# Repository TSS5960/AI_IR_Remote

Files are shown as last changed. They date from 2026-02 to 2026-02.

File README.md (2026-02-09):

# ESP32-S3 Smart AC Remote Control with Voice Integration

An intelligent air conditioner remote control system based on ESP32-S3 with voice wake word detection (Edge Impulse), IR learning, cloud connectivity, and multi-sensor integration.

## Features

### Core Functionality
- **WiFi Captive Portal**: Easy WiFi setup via web interface (no hardcoded credentials)
- **IR Control**: Send IR commands to control air conditioners (10+ brands supported)
- **IR Learning**: Capture and replay any IR remote signals (up to 40 signals)
- **Voice Wake Word**: "Hey Bob" wake word detection using Edge Impulse ML
- **Multi-Screen Display**: TFT interface with 7 different screens
- **Environmental Monitoring**: Temperature, humidity, light, and motion sensors
- **Cloud Integration**: MQTT broker and Firebase real-time database
- **Web Dashboard**: Cloudflare-hosted control panel
- **Alarm System**: Time-based alarms with speaker notifications

### Voice Features
- **Edge Impulse Wake Word**: On-device ML model for "Hey Bob" detection
  - Runs entirely on ESP32 (no cloud required)
  - ~100ms inference latency
  - Adjustable confidence threshold (default 80%)
- **Speech Recognition**: Experimental integration with Groq console
  - Uses console.groq.com for speech-to-text transcription
  - Currently in experimental phase
  - Requires internet connection
- **Record & Playback**: 3-second audio recording with instant playback
- **Voice Level Monitor**: Real-time audio RMS visualization
- **LED Feedback**: NeoPixel RGB LED indicates wake word detection and processing states

## Hardware Components

### Main Controller
- **ESP32-S3-N16R8** - Dual-core 240MHz with 16MB Flash, 8MB PSRAM

### Audio System
- **INMP441 I2S MEMS Microphone** (GPIO4=WS, GPIO5=SCK, GPIO6=SD)
- **MAX98357 I2S Amplifier + Speaker** (GPIO15=BCLK, GPIO16=LRCLK, GPIO7=DIN)
- **Adafruit NeoPixel RGB LED** (GPIO48)

### Display & Input
- **ST7789 TFT Display** (240x280, SPI)
- **Analog Joystick** (X/Y axes + button)

### Sensors
- **BH1750 Light Sensor** (I2C)
- **DHT11 Temperature & Humidity Sensor**
- **PIR Motion Sensor**

### IR System
- **IR Transmitter LED** (GPIO12)
- **IR Receiver Module** (GPIO11)

## Project Structure

```
AC_IR_Remote/
├── AC_IR_Remote.ino          # Main firmware
├── config.h                   # Pin assignments and configuration
├── secrets.h                  # Firebase credentials (not in git)
├── secrets.h.template         # Template for secrets configuration
├── firebase_config.h          # Firebase paths (not in git)
├── firebase_config.h.template # Template for Firebase configuration
│
├── # Core modules
├── ac_control.cpp/h           # AC IR control logic
├── ir_control.cpp/h           # IR transmitter/receiver
├── ir_learning_enhanced.cpp/h # Enhanced IR learning mode
├── mic_control.cpp/h          # Microphone I2S driver
├── speaker_control.cpp/h      # Audio playback
├── button_control.cpp/h       # Joystick input handling
├── display.cpp/h              # TFT screen management
├── sensors.cpp/h              # Environmental sensors
├── alarm_manager.cpp/h        # Alarm system
│
├── # Edge Impulse Wake Word
├── ei_wake_word.cpp/h         # Edge Impulse integration
│
├── # Network modules
├── wifi_manager.cpp/h         # WiFi connectivity
├── mqtt_broker.cpp/h          # MQTT client
├── firebase_client.cpp/h      # Firebase integration
│
├── # Training Tools
├── EiWakeWordTraining/        # Audio sample collection tools
│   ├── audio_capture.ino      # ESP32 sketch for recording samples
│   └── capture_samples.py     # Python script to save WAV files
│
├── guide/                     # Documentation (gitignored)
│   └── EDGE_IMPULSE_GUIDE.md  # Complete Edge Impulse setup guide
│
└── cloudflare_dashboard/      # Web dashboard
    ├── src/index.js           # Cloudflare Worker
    ├── public/
    │   ├── index.html         # Dashboard UI
    │   ├── app.js             # Frontend logic
    │   └── styles.css         # Styling
    ├── wrangler.toml          # Cloudflare configuration (not in git)
    └── wrangler.toml.template # Template for Cloudflare configuration
```

## Getting Started

### 1. Hardware Setup

**Display (ST7789 240x280):**
```
ST7789 TFT → ESP32-S3
  VCC  → 3.3V
  GND  → GND
  MOSI → GPIO47
  SCLK → GPIO21
  DC   → GPIO40
  RST  → GPIO45
  BL   → GPIO42
  CS   → Not connected (directly enabled)
```

**Audio System:**
```
INMP441 Microphone → ESP32-S3
  VDD → 3.3V
  GND → GND
  WS  → GPIO4
  SCK → GPIO5
  SD  → GPIO6
  L/R → GND

MAX98357 Amplifier → ESP32-S3
  VIN  → 5V
  GND  → GND
  BCLK → GPIO15
  LRC  → GPIO16
  DIN  → GPIO7

NeoPixel RGB LED → ESP32-S3
  VDD → 5V
  GND → GND
  DIN → GPIO48
```

**IR System:**
```
IR Transmitter → ESP32-S3
  VCC → 3.3V
  GND → GND
  DAT → GPIO8

IR Receiver → ESP32-S3
  VCC → 3.3V
  GND → GND
  OUT → GPIO9
```

**Sensors:**
```
DHT11 → ESP32-S3
  VCC  → 3.3V
  GND  → GND
  DATA → GPIO17

BH1750 Light Sensor → ESP32-S3
  VCC → 3.3V
  GND → GND
  SDA → GPIO14
  SCL → GPIO13

PIR Motion Sensor → ESP32-S3
  VCC → 5V
  GND → GND
  OUT → GPIO10
```

**Joystick:**
```
Analog Joystick → ESP32-S3
  VCC → 3.3V
  GND → GND
  VRx → GPIO1
  VRy → GPIO2
  SW  → GPIO18
```

### 2. Software Setup

#### Arduino IDE Configuration
1. Install ESP32 board support: https://espressif.github.io/arduino-esp32/
2. Select Board: **ESP32S3 Dev Module**
3. Install required libraries:
   - `Adafruit_NeoPixel`
   - `TFT_eSPI`
   - `IRremoteESP8266`
   - `DHT sensor library`
   - `BH1750`
   - `Firebase ESP32 Client`
   - `PubSubClient`
   - **Edge Impulse library** (see Wake Word Setup below)

#### TFT_eSPI Library Configuration

**Important:** The TFT_eSPI library requires manual pin configuration inside the library folder. (Don't ask me why, ask the creator of this library: https://github.com/Bodmer/TFT_eSPI)

1. Navigate to your Arduino libraries folder:
   ```
   Windows: C:\Users\<username>\Documents\Arduino\libraries\TFT_eSPI\
   Mac/Linux: ~/Arduino/libraries/TFT_eSPI/
   ```

2. Open `User_Setup.h` and make these changes:

   ```cpp
   // Comment out the default driver and enable ST7789:
   // #define ILI9341_DRIVER
   #define ST7789_DRIVER

   // Set display size (240x280 for this project):
   #define TFT_WIDTH  240
   #define TFT_HEIGHT 280

   // Define the pins for ESP32-S3:
   #define TFT_MOSI 47
   #define TFT_SCLK 21
   #define TFT_CS   -1  // Not used (directly connected)
   #define TFT_DC   40
   #define TFT_RST  45
   #define TFT_BL   42  // Backlight (optional, controlled in code)

   // Enable hardware SPI:
   #define USE_HSPI_PORT
   ```

3. Save the file and restart Arduino IDE.

**Note:** Backlight control is handled separately in `config.h` via `TFT_BL_PIN`.

#### Upload Firmware
1. Connect ESP32-S3 via USB
2. Select correct port in Arduino IDE
3. Upload `AC_IR_Remote.ino`
4. Open Serial Monitor at **115200 baud**

### 3. Wake Word Setup (Edge Impulse)

The wake word detection uses Edge Impulse for on-device machine learning. Follow these steps to train your own "Hey Bob" model:

#### Step 1: Collect Training Samples

Use the tools in `EiWakeWordTraining/` folder:

1. **Upload the capture sketch:**
   ```
   Open EiWakeWordTraining/audio_capture.ino in Arduino IDE
   Upload to ESP32
   Close Serial Monitor after upload
   ```

2. **Install Python dependencies:**
   ```bash
   pip install pyserial
   ```

3. **Run the capture script:**
   ```bash
   cd EiWakeWordTraining
   python capture_samples.py
   ```

4. **Record samples interactively:**
   ```
   Commands:
     1 or h  - Record 'hey_bob' sample (say "Hey Bob")
     2 or n  - Record 'noise' sample (background sounds)
     3 or u  - Record 'unknown' sample (other words)
     t       - Test microphone level
     s       - Show sample counts
     q       - Quit
   ```

5. **Recommended sample counts:**
   - `hey_bob`: 50-100 samples (vary your voice, distance, speed)
   - `noise`: 200+ samples (silence, fan noise, TV, typing)
   - `unknown`: 30-50 samples ("Hello", "Hey John", "OK Google", etc.)

6. **Samples are saved to:** `EiWakeWordTraining/training_samples/`

**Important:** Close Arduino IDE Serial Monitor before running Python script - only one program can use the COM port.

#### Step 2: Train on Edge Impulse

1. Create account at [edgeimpulse.com](https://edgeimpulse.com)
2. Create new project: "Hey Bob Wake Word"
3. Upload WAV files from `training_samples/` folders with correct labels
4. Create Impulse:
   - Window size: 1500ms, Stride: 500ms, Frequency: 16000Hz
   - Processing: Audio (MFCC)
   - Learning: Classification or Transfer Learning
5. Train model (target >90% accuracy)
6. Deploy as Arduino library (Quantized int8)
7. Download the `.zip` file

#### Step 3: Install Library

1. In Arduino IDE: **Sketch** → **Include Library** → **Add .ZIP Library**
2. Select the downloaded Edge Impulse library
3. Re-upload `AC_IR_Remote.ino`

The wake word detection will automatically start on boot.

### 4. WiFi Setup (Captive Portal)

1. **First boot** - ESP32 creates WiFi AP: `ESP32_AC_Remote`
2. **Connect to AP** - WiFi password: `12345678`
3. **Configure WiFi** - Browser auto-opens configuration page
   - If not, navigate to `http://192.168.4.1`
   - Enter your WiFi SSID and password
4. **Device reboots** and connects to your WiFi network

### 5. Firebase Setup

1. Copy templates:
   ```bash
   cp firebase_config.h.template firebase_config.h
   cp secrets.h.template secrets.h
   ```

2. Edit with your Firebase credentials

## Usage

### Serial Commands

**Wake Word (Edge Impulse):**
- `voice` - Show real-time voice level monitor
- `repeat` - Record 3 seconds and play back
- `wake_start` - Start wake word detection
- `wake_stop` - Stop wake word detection
- `wake_threshold` - Show current confidence threshold
- `wake_threshold N` - Set threshold (0-100%)

**IR Commands:**
- `learn` - Enter IR learning mode
- `I1` to `I40` - Send learned IR signal 1-40
- `irtest` - Test IR receiver

**AC Control:**
- `1` / `0` - Turn AC on/off
- `+` / `-` - Increase/decrease temperature
- `m` - Cycle through modes (cool/heat/dry/fan/auto)
- `f` - Cycle through fan speeds

**System Commands:**
- `h` - Show help
- `s` - Show system status
- `test` - Test speaker

**Alarm Management:**
- `a HH MM [name]` - Add alarm (e.g., `a 07 30 Morning`)
- `u INDEX HH MM [name]` - Update alarm
- `d INDEX` - Delete alarm
- `p` - List all alarms

### Display Screens

Navigate using joystick (left/right):
1. **Volume** - Speaker volume control
2. **Clock** - Current time display
3. **Network** - WiFi and Firebase status
4. **AC Control** - Temperature and mode
5. **IR Learn** - IR learning interface
6. **Sensors** - Environmental data
7. **Alarm** - Active alarm display

### Wake Word Detection

When "Hey Bob" is detected:
1. Serial prints detection with confidence percentage
2. NeoPixel LED turns blue
3. Confirmation beep plays
4. Voice command recording starts (blue LED, stops after 5 seconds of inactivity)
5. Audio is sent to Groq Whisper API for transcription
6. Text is sent to LLaMA 3.1 8B for intent parsing
7. Actions executed (AC control, IR signals) with voice feedback
8. White LED flash, then returns to wake word listening

**Current Status**: Wake word detection ✅ | Speech recognition ✅ | Intent parsing ✅ | Command execution ✅ (experimental)

**Tuning Tips:**
- Default threshold is 80% - increase if too many false positives
- Use `wake_threshold 90` for stricter detection
- Use `wake_threshold 70` if it's not detecting well
- Retrain model with more samples if accuracy is poor

## Technical Details

### Edge Impulse Wake Word
- **Model**: MFCC + Neural Network (Classification)
- **Sample Rate**: 16kHz mono
- **Window Size**: 1500ms
- **Inference**: ~100ms on ESP32-S3
- **Threshold**: 80% confidence (adjustable)
- **Cooldown**: 2 seconds between detections

### MQTT Topics
- **Publish**: `ac/status` - Device status updates
- **Subscribe**: `ac/command` - Remote commands

### Memory Usage
- Edge Impulse model: ~50-100KB (quantized int8)
- Audio inference buffer: ~48KB

## Troubleshooting

### Wake Word Not Detecting
- Check microphone connections (WS=4, SCK=5, SD=6)
- Use `voice` command to verify audio levels
- Lower threshold: `wake_threshold 70`
- Retrain model with more samples from your environment

### Too Many False Positives
- Increase threshold: `wake_threshold 90`
- Add more "noise" samples to training data
- Add more "unknown" speech samples

### Microphone Issues
- Ensure L/R pin connected to GND (left channel)
- Verify 3.3V power supply
- Check for I2S conflicts with speaker

### WiFi Connection Failed
- Reset WiFi using joystick double-click on Network screen
- Ensure 2.4GHz WiFi (ESP32 doesn't support 5GHz)
- Connect to AP (`12345678`) and reconfigure

## Pin Configuration (config.h)

```cpp
// Microphone (INMP441)
#define MIC_WS_PIN 4
#define MIC_SCK_PIN 5
#define MIC_SD_PIN 6

// Speaker (MAX98357)
#define SPK_BCLK_PIN 15
#define SPK_LRCLK_PIN 16
#define SPK_SD_PIN 7

// NeoPixel LED
#define NEOPIXEL_PIN 48

// IR
#define IR_TX_PIN 12
#define IR_RX_PIN 11
```

## Voice Command Pipeline (Experimental)

### Current Status

**All core features implemented - testing and improving reliability:**

- ✅ **Wake Word Detection**: "Hey Bob" detection (Edge Impulse)
- ✅ **Speech Recognition**: Groq Whisper API (whisper-large-v3)
- ✅ **Intent Parsing**: Groq LLaMA 3.1 8B (llama-3.1-8b-instant)
- ✅ **JSON Response**: Structured action parsing
- ✅ **Action Execution**: AC control, IR signals
- ✅ **Voice Feedback**: Audio responses via speaker

**Experimental - Still improving:**
- Silence detection threshold tuning
- Response reliability optimization
- Error handling improvements

### Supported Voice Commands

**AC Control:**
| Command Example | Action |
|---|---|
| "Turn on the AC" | Powers on AC (uses last selected brand) |
| "Turn on the Samsung AC" | Switches to Samsung, then powers on |
| "Set temperature to 24 degrees" | Sets AC to 24°C |
| "Switch to cooling mode" | Changes to cool mode |
| "Turn off the AC" | Powers off AC |
| "It's too hot" | Turns on AC + cool mode |

**IR Device Control (Dynamic):**
The system automatically tells the AI what IR signals you have registered. Just name your signals descriptively!

| Signal Name Example | Voice Command |
|---|---|
| `BedroomLightOn` | "Turn on the bedroom light" |
| `LivingRoomLightOff` | "Turn off the living room light" |
| `TVPower` | "Turn on the TV" |
| `FanToggle` | "Toggle the fan" |

**Multi-Brand AC Support:**
Daikin, Mitsubishi, Panasonic, Gree, Midea, Haier, Samsung, LG, Fujitsu, Hitachi

**Setup for IR Devices:**
1. Learn your remote's IR signals: `learn`
2. Name them descriptively: `setname 0 BedroomLightOn`
3. Say "Hey Bob, turn on the bedroom light"

The AI sees your registered signals and decides which one to send!

### Architecture

```
┌─────────────┐    ┌─────────────┐    ┌─────────────┐    ┌─────────────┐
│ Wake Word   │ →  │ Recording   │ →  │ Whisper     │ →  │ LLaMA 3.1   │
│ "Hey Bob"   │    │ Blue LED    │    │ STT API     │    │ 8B Intent   │
│ (Edge       │    │ 5s silence  │    │ (Groq)      │    │ Parser      │
│ Impulse)    │    │ detection   │    │             │    │ (Groq)      │
└─────────────┘    └─────────────┘    └─────────────┘    └─────────────┘
                                                                │
                                                                ▼
┌─────────────┐    ┌─────────────┐    ┌─────────────┐    ┌─────────────┐
│ Resume      │ ←  │ Voice       │ ←  │ Execute     │ ←  │ JSON        │
│ Wake Word   │    │ Feedback    │    │ Actions     │    │ Response    │
│ Detection   │    │ Speaker     │    │ AC/IR       │    │ {actions:[]}│
└─────────────┘    └─────────────┘    └─────────────┘    └─────────────┘
```

### Flow

1. **Wake Word**: "Hey Bob" detected → beep confirmation
2. **Recording**: Blue LED on, record until 5s silence
3. **Processing**: Send audio to Groq Whisper → get text
4. **Intent Parsing**: Send text to LLaMA 3.1 8B → get JSON actions
5. **Execute**: Run actions (AC control, IR signals)
6. **Feedback**: Voice response ("Power on", "24 degrees", etc.)
7. **Resume**: White LED flash → back to wake word listening

### Configuration

API credentials in `groq_config.h` (gitignored):
```cpp
#define GROQ_API_KEY "gsk_your_key_here"
#define GROQ_WHISPER_MODEL "whisper-large-v3"
#define GROQ_LLM_MODEL "llama-3.1-8b-instant"
```

See `guide/GROQ_LLM_SETUP.md` for detailed setup instructions.

## Future Enhancements

### Additional Voice Features
- **Groq API**: Free tier, very fast inference (LLaMA 3 8B)
- **Google Gemini API**: Free tier (15 RPM, 1M tokens/day)
- **Cloudflare Workers AI**: Free tier (10K tokens/day)
- **Ollama (self-hosted)**: Free, run LLaMA on your own server/PC

**Example LLM Prompt:**
```
You are a smart home assistant. Parse the user command and return JSON.
Available actions: ac_on, ac_off, ac_temp, ac_mode, ir_send, light_on, light_off

User: "turn on the AC and set it to 24 degrees"
Response: {"actions": [{"type": "ac_on"}, {"type": "ac_temp", "value": 24}]}
```

**Text-to-Speech Response:**
- **Google Cloud TTS API**: Natural voices, multiple languages
- **OpenAI TTS API**: Very natural, simple to use
- **Eleven Labs API**: High quality voice cloning
- **ESP32 local TTS**: Basic robotic voice, no cloud needed

### Smart Home API Integration

Use cloud APIs to control WiFi-compatible smart devices:

**Google Home API**
- Control Google Home compatible devices via API
- Works with Nest, Philips Hue, TP-Link, etc.
- OAuth2 authentication required

**Amazon Alexa API**
- Smart Home Skill API for device control
- Works with Ring, Ecobee, Sengled, etc.

**Tuya/Smart Life API**
- Control thousands of cheap WiFi devices
- Plugs, lights, switches, sensors
- Local API available (no cloud dependency)

**IFTTT Webhooks**
- Trigger any IFTTT applet via HTTP
- Connect to 700+ services

### Zigbee Integration
- **Zigbee Coordinator**: Add CC2652 or EFR32 Zigbee module
- **Zigbee2MQTT Bridge**: Control Zigbee devices through existing MQTT
- **Device Support**:
  - Smart plugs and switches
  - Light bulbs (Philips Hue, IKEA Tradfri)
  - Sensors (door/window, motion, temperature)
- **Local Control**: No cloud dependency, mesh network

### Additional Protocols
- **Matter**: Universal smart home standard (Google, Apple, Amazon compatible)
- **Bluetooth Mesh**: BLE-based device control
- **Thread**: IPv6-based mesh networking

### Advanced Voice Features
- **Multi-Wake Word**: Train additional wake words
- **Speaker Identification**: Recognize different users
- **Multi-language**: Train models for different languages

### Automation
- **Scene Control**: "Movie time" → Dim lights, set AC to 24°C
- **Scheduled Routines**: Time-based automation
- **Sensor Triggers**: Auto-adjust based on environment

## License

This project is open source and available for educational purposes.

## Author

Sheng

---

**Note**: This project uses Edge Impulse for on-device wake word detection. The ML model runs entirely on the ESP32 without requiring cloud connectivity for voice detection, however the rest part of the project needs wifi to be working.

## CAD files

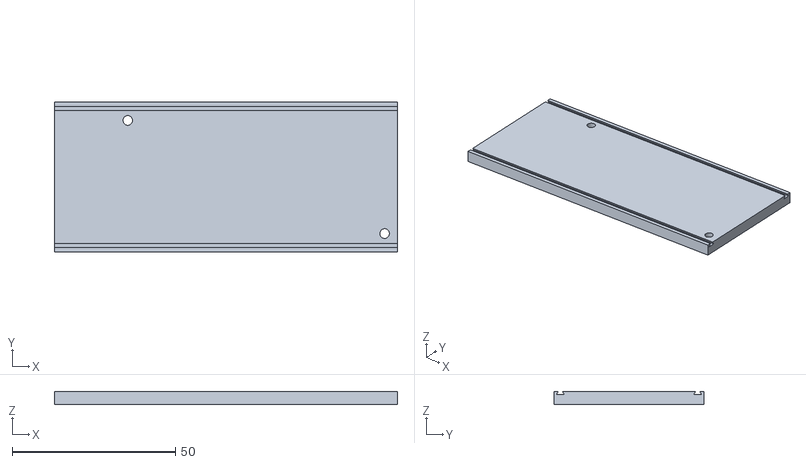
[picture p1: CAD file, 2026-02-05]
hardware/FYP-Enclosure_Bottom.stl
105.0 x 46.0 x 4.00

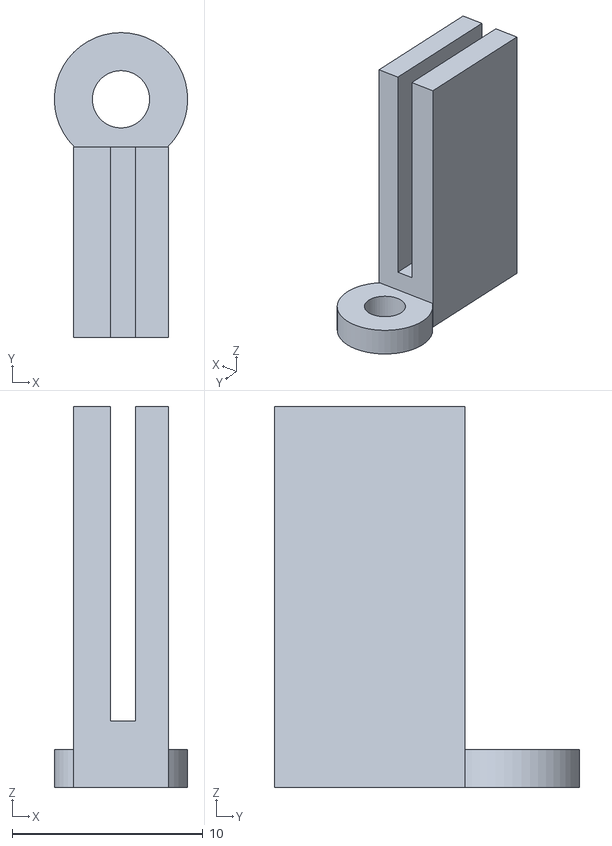
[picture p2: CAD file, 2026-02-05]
hardware/FYP-Enclosure_Holder.stl
7.00 x 16.0 x 20.0

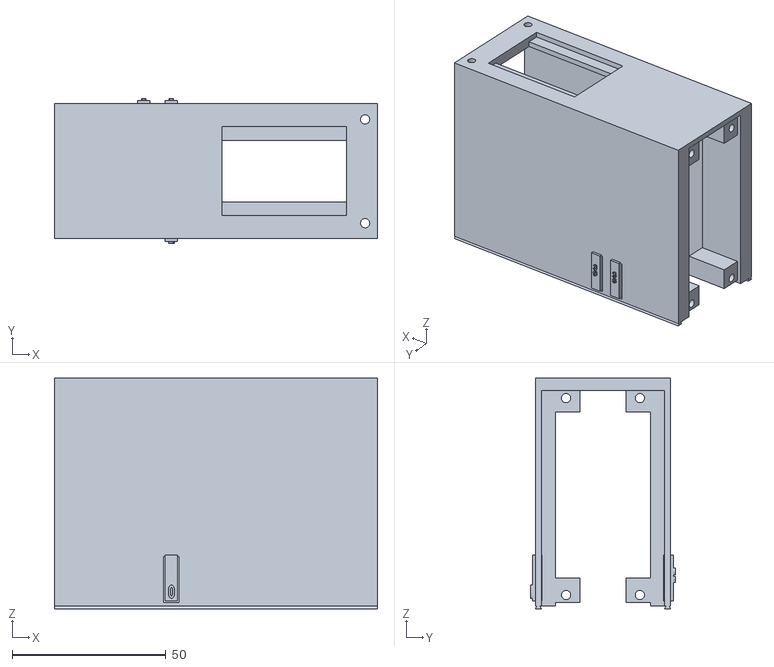
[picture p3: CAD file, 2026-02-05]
hardware/FYP-Enclosure_Body.stl
105.0 x 47.0 x 75.0

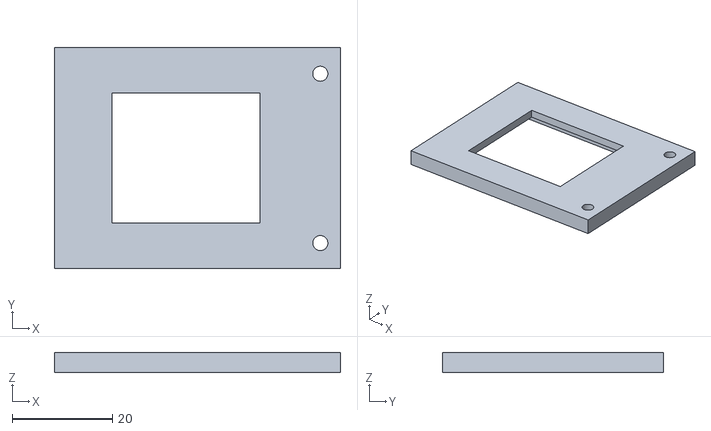
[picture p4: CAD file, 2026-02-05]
hardware/FYP-Enclosure_Top.stl
57.0 x 44.0 x 4.00

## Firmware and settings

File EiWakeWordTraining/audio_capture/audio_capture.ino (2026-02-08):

/*
 * Audio Capture for Edge Impulse Training
 *
 * This is a standalone sketch for collecting audio samples
 * to train your "Hey Bob" wake word model on Edge Impulse.
 *
 * Hardware: ESP32 + INMP441 I2S Microphone
 * Pins: WS=GPIO4, SCK=GPIO5, SD=GPIO6
 *
 * Usage:
 * 1. Upload this sketch to ESP32
 * 2. Open Serial Monitor (115200 baud)
 * 3. Use commands to record samples:
 *    - "hey_bob"  : Record wake word sample
 *    - "noise"    : Record background noise
 *    - "unknown"  : Record other speech
 *    - "test"     : Test microphone levels
 * 4. Run capture_samples.py on PC to save WAV files
 * 5. Upload WAV files to Edge Impulse
 */

#include <driver/i2s.h>

// ========== Pin Configuration ==========
#define MIC_WS_PIN    4     // Word Select (LRCLK)
#define MIC_SCK_PIN   5     // Serial Clock (BCLK)
#define MIC_SD_PIN    6     // Serial Data (DOUT)

// ========== Audio Configuration ==========
#define SAMPLE_RATE     16000   // 16kHz - matches Edge Impulse default
#define DURATION_MS     1500    // 1.5 seconds per sample
#define TOTAL_SAMPLES   (SAMPLE_RATE * DURATION_MS / 1000)  // 24000 samples

// I2S configuration
#define I2S_PORT I2S_NUM_0

// ========== Global Variables ==========
static bool micInitialized = false;
static String currentLabel = "";

// ========== Function Declarations ==========
bool initMicrophone();
void recordAndOutputWAV(const char* label);
void testMicrophoneLevel();
size_t readAudioSamples(int16_t* buffer, size_t count);

// ========== Setup ==========
void setup() {
  Serial.begin(115200);
  delay(1000);

  Serial.println("\n");
  Serial.println("========================================");
  Serial.println("  Edge Impulse Audio Capture Tool");
  Serial.println("  For 'Hey Bob' Wake Word Training");
  Serial.println("========================================");
  Serial.println();

  // Initialize microphone
  if (initMicrophone()) {
    Serial.println("[OK] Microphone initialized");
  } else {
    Serial.println("[ERROR] Microphone initialization failed!");
    Serial.println("Check wiring: WS=GPIO4, SCK=GPIO5, SD=GPIO6");
  }

  Serial.println();
  Serial.println("Commands:");
  Serial.println("  hey_bob  - Record wake word sample");
  Serial.println("  noise    - Record background noise");
  Serial.println("  unknown  - Record other speech/words");
  Serial.println("  test     - Test microphone levels");
  Serial.println();
  Serial.println("Waiting for command...");
}

// ========== Main Loop ==========
void loop() {
  if (Serial.available()) {
    String command = Serial.readStringUntil('\n');
    command.trim();
    command.toLowerCase();

    if (command == "hey_bob" || command == "heybob") {
      recordAndOutputWAV("hey_bob");
    }
    else if (command == "noise" || command == "background") {
      recordAndOutputWAV("noise");
    }
    else if (command == "unknown" || command == "other") {
      recordAndOutputWAV("unknown");
    }
    else if (command == "test" || command == "mic_test") {
      testMicrophoneLevel();
    }
    else if (command == "help") {
      Serial.println("\nCommands:");
      Serial.println("  hey_bob  - Record wake word sample");
      Serial.println("  noise    - Record background noise");
      Serial.println("  unknown  - Record other speech/words");
      Serial.println("  test     - Test microphone levels");
    }
    else if (command.length() > 0) {
      Serial.printf("Unknown command: %s\n", command.c_str());
      Serial.println("Type 'help' for available commands");
    }
  }
}

// ========== Microphone Initialization ==========
bool initMicrophone() {
  // I2S configuration for INMP441
  i2s_config_t i2s_config = {
    .mode = (i2s_mode_t)(I2S_MODE_MASTER | I2S_MODE_RX),
    .sample_rate = SAMPLE_RATE,
    .bits_per_sample = I2S_BITS_PER_SAMPLE_32BIT,  // INMP441 outputs 32-bit
    .channel_format = I2S_CHANNEL_FMT_ONLY_LEFT,
    .communication_format = I2S_COMM_FORMAT_STAND_I2S,
    .intr_alloc_flags = ESP_INTR_FLAG_LEVEL1,
    .dma_buf_count = 8,
    .dma_buf_len = 256,
    .use_apll = false,
    .tx_desc_auto_clear = false,
    .fixed_mclk = 0
  };

  // Pin configuration
  i2s_pin_config_t pin_config = {
    .bck_io_num = MIC_SCK_PIN,
    .ws_io_num = MIC_WS_PIN,
    .data_out_num = I2S_PIN_NO_CHANGE,
    .data_in_num = MIC_SD_PIN
  };

  // Install and configure I2S driver
  esp_err_t err = i2s_driver_install(I2S_PORT, &i2s_config, 0, NULL);
  if (err != ESP_OK) {
    Serial.printf("I2S driver install failed: %d\n", err);
    return false;
  }

  err = i2s_set_pin(I2S_PORT, &pin_config);
  if (err != ESP_OK) {
    Serial.printf("I2S pin config failed: %d\n", err);
    i2s_driver_uninstall(I2S_PORT);
    return false;
  }

  // Start I2S
  i2s_start(I2S_PORT);
  i2s_zero_dma_buffer(I2S_PORT);

  micInitialized = true;
  return true;
}

// ========== Read Audio Samples ==========
size_t readAudioSamples(int16_t* buffer, size_t count) {
  size_t samplesRead = 0;
  int32_t sample32;
  size_t bytesRead;

  for (size_t i = 0; i < count; i++) {
    esp_err_t err = i2s_read(I2S_PORT, &sample32, sizeof(int32_t), &bytesRead, portMAX_DELAY);
    if (err != ESP_OK || bytesRead != sizeof(int32_t)) {
      break;
    }
    // Convert 32-bit to 16-bit (take upper 16 bits)
    buffer[i] = (int16_t)(sample32 >> 16);
    samplesRead++;
  }

  return samplesRead;
}

// ========== Record and Output WAV ==========
void recordAndOutputWAV(const char* label) {
  if (!micInitialized) {
    Serial.println("[ERROR] Microphone not initialized!");
    return;
  }

  // Allocate buffer for recording
  int16_t* samples = (int16_t*)malloc(TOTAL_SAMPLES * sizeof(int16_t));
  if (!samples) {
    Serial.println("[ERROR] Memory allocation failed!");
    Serial.printf("Needed: %d bytes\n", TOTAL_SAMPLES * sizeof(int16_t));
    return;
  }

  Serial.println();
  Serial.printf("=== Recording '%s' sample ===\n", label);
  Serial.println("Get ready...");
  delay(500);

  Serial.println("3...");
  delay(500);
  Serial.println("2...");
  delay(500);
  Serial.println("1...");
  delay(500);

  if (strcmp(label, "hey_bob") == 0) {
    Serial.println(">>> SAY 'HEY BOB' NOW! <<<");
  } else if (strcmp(label, "noise") == 0) {
    Serial.println(">>> RECORDING BACKGROUND NOISE <<<");
  } else {
    Serial.println(">>> SPEAK NOW! <<<");
  }

  // Record audio
  size_t samplesRecorded = 0;
  const size_t chunkSize = 512;
  int16_t chunk[chunkSize];
  unsigned long startTime = millis();

  while (samplesRecorded < TOTAL_SAMPLES) {
    size_t toRead = min(chunkSize, (size_t)(TOTAL_SAMPLES - samplesRecorded));
    size_t read = readAudioSamples(chunk, toRead);

    if (read > 0) {
      memcpy(&samples[samplesRecorded], chunk, read * sizeof(int16_t));
      samplesRecorded += read;

      // Progress dots
      if (samplesRecorded % 4000 == 0) {
        Serial.print(".");
      }
    }
  }

  unsigned long recordTime = millis() - startTime;
  Serial.println();
  Serial.printf("Recorded %d samples in %lu ms\n", samplesRecorded, recordTime);

  // Output WAV data
  Serial.println();
  Serial.println("Outputting WAV data...");
  Serial.printf("---WAV_START:%s---\n", label);

  // WAV header (44 bytes)
  uint32_t dataSize = TOTAL_SAMPLES * sizeof(int16_t);
  uint32_t fileSize = 36 + dataSize;

  uint8_t header[44] = {
    // RIFF header
    'R', 'I', 'F', 'F',
    (uint8_t)(fileSize & 0xFF),
    (uint8_t)((fileSize >> 8) & 0xFF),
    (uint8_t)((fileSize >> 16) & 0xFF),
    (uint8_t)((fileSize >> 24) & 0xFF),
    'W', 'A', 'V', 'E',

    // fmt subchunk
    'f', 'm', 't', ' ',
    16, 0, 0, 0,              // Subchunk1 size (16 for PCM)
    1, 0,                      // Audio format (1 = PCM)
    1, 0,                      // Number of channels (1 = mono)
    (uint8_t)(SAMPLE_RATE & 0xFF),
    (uint8_t)((SAMPLE_RATE >> 8) & 0xFF),
    (uint8_t)((SAMPLE_RATE >> 16) & 0xFF),
    (uint8_t)((SAMPLE_RATE >> 24) & 0xFF),
    (uint8_t)((SAMPLE_RATE * 2) & 0xFF),      // Byte rate
    (uint8_t)(((SAMPLE_RATE * 2) >> 8) & 0xFF),
    (uint8_t)(((SAMPLE_RATE * 2) >> 16) & 0xFF),
    (uint8_t)(((SAMPLE_RATE * 2) >> 24) & 0xFF),
    2, 0,                      // Block align
    16, 0,                     // Bits per sample

    // data subchunk
    'd', 'a', 't', 'a',
    (uint8_t)(dataSize & 0xFF),
    (uint8_t)((dataSize >> 8) & 0xFF),
    (uint8_t)((dataSize >> 16) & 0xFF),
    (uint8_t)((dataSize >> 24) & 0xFF)
  };

  // Output header as hex
  for (int i = 0; i < 44; i++) {
    Serial.printf("%02X", header[i]);
  }

  // Output audio data as hex (little-endian)
  for (size_t i = 0; i < TOTAL_SAMPLES; i++) {
    Serial.printf("%02X%02X", samples[i] & 0xFF, (samples[i] >> 8) & 0xFF);

    // Yield periodically to prevent watchdog timeout
    if (i % 1000 == 0) {
      yield();
    }
  }

  Serial.println();
  Serial.println("---WAV_END---");
  Serial.println();

  // Free memory
  free(samples);

  Serial.printf("[OK] '%s' sample complete!\n", label);
  Serial.println("Run capture_samples.py on PC to save the WAV file");
  Serial.println();
  Serial.println("Waiting for next command...");
}

// ========== Test Microphone Level ==========
void testMicrophoneLevel() {
  if (!micInitialized) {
    Serial.println("[ERROR] Microphone not initialized!");
    return;
  }

  Serial.println();
  Serial.println("=== Microphone Level Test ===");
  Serial.println("Speak to see audio levels");
  Serial.println("Press any key to stop");
  Serial.println();

  const size_t sampleCount = 256;
  int16_t samples[sampleCount];

  unsigned long testDuration = 10000;  // 10 seconds
  unsigned long startTime = millis();

  while (millis() - startTime < testDuration) {
    // Check for stop command
    if (Serial.available()) {
      Serial.read();
      break;
    }

    // Read samples
    size_t read = readAudioSamples(samples, sampleCount);

    if (read > 0) {
      // Calculate RMS level
      int64_t sum = 0;
      for (size_t i = 0; i < read; i++) {
        int32_t val = samples[i];
        sum += val * val;
      }
      int32_t rms = sqrt(sum / read);
      int level = (rms * 100) / 32768;
      level = constrain(level, 0, 100);

      // Display bar graph
      Serial.printf("Level: %3d%% [", level);
      int bars = level / 2;
      for (int i = 0; i < 50; i++) {
        Serial.print(i < bars ? "=" : " ");
      }
      Serial.println("]");
    }

    delay(100);
  }

  Serial.println();
  Serial.println("Microphone test complete");
  Serial.println("Waiting for next command...");
}

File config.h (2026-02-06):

/*
 * Configuration File
 * Pin definitions and constants
 */

#ifndef CONFIG_H
#define CONFIG_H

#include <Arduino.h>

// ========== Feature Flags ==========

// Set to 1 to enable legacy AWS IoT module
#define USE_AWS_IOT 0

// Set to 1 to enable MQTT broker control (EMQX public broker by default)
#define USE_MQTT_BROKER 1

// ========== MQTT Broker Configuration ==========

#define MQTT_BROKER_HOST "broker.emqx.io"
#define MQTT_BROKER_PORT 1883
#define MQTT_PUBLISH_TOPIC "ac/status"
#define MQTT_SUBSCRIBE_TOPIC "ac/command"
#define MQTT_CLIENT_ID "ESP32_AC_Remote_001"

// ========== Pin Definitions ==========

// Display pins (ST7789)
#define TFT_BL_PIN    42    // Backlight
// Other pins defined in User_Setup.h
// SCLK: 21, MOSI: 47, DC: 40, RST: 45

// IR pins
#define IR_TX_PIN     8     // IR transmitter
#define IR_RX_PIN     9     // IR receiver

// Sensor pins
#define PIR_PIN       10    // PIR motion sensor
#define DHT_PIN       17    // DHT11 temperature & humidity sensor
#define GY30_SDA_PIN  14    // GY-30 (BH1750) I2C data
#define GY30_SCL_PIN  13    // GY-30 (BH1750) I2C clock

// Speaker pins (I2S MAX98357)
#define SPK_SD_PIN    7     // Speaker DIN (data)
#define SPK_BCLK_PIN  15    // Speaker BCLK (bit clock)
#define SPK_LRCLK_PIN 16    // Speaker LRCLK (left-right clock)

// Microphone pins (INMP441 I2S)
#define MIC_WS_PIN    4     // Word Select (LRCLK)
#define MIC_SCK_PIN   5     // Serial Clock (BCLK)
#define MIC_SD_PIN    6     // Serial Data (DOUT)

// NeoPixel RGB LED pin
#define NEOPIXEL_PIN  48    // WS2812 RGB LED data pin
#define NEOPIXEL_COUNT 1    // Number of NeoPixels

// ========== AC Parameters ==========

#define AC_TEMP_MIN   16    // Minimum temperature
#define AC_TEMP_MAX   30    // Maximum temperature
#define AC_TEMP_DEFAULT 24  // Default temperature

// Auto dry mode (humidity threshold)
#define AUTO_DRY_THRESHOLD_DEFAULT 65
#define AUTO_DRY_THRESHOLD_MIN 40
#define AUTO_DRY_THRESHOLD_MAX 85
#define AUTO_DRY_HYSTERESIS 3

// Sleep mode (light threshold to lower fan speed)
#define SLEEP_LIGHT_THRESHOLD_DEFAULT 30
#define SLEEP_LIGHT_THRESHOLD_MIN 1
#define SLEEP_LIGHT_THRESHOLD_MAX 1000
#define SLEEP_LIGHT_HYSTERESIS 5

// AC modes
enum ACMode {
  MODE_AUTO = 0,    // Auto
  MODE_COOL = 1,    // Cooling
  MODE_HEAT = 2,    // Heating
  MODE_DRY = 3,     // Dehumidify
  MODE_FAN = 4      // Fan only
};

// Fan speeds
enum FanSpeed {
  FAN_AUTO = 0,     // Auto
  FAN_LOW = 1,      // Low
  FAN_MED = 2,      // Medium
  FAN_HIGH = 3      // High
};

// Supported AC brands
enum ACBrand {
  BRAND_DAIKIN = 0,      // Daikin
  BRAND_MITSUBISHI,      // Mitsubishi
  BRAND_PANASONIC,       // Panasonic
  BRAND_GREE,            // Gree
  BRAND_MIDEA,           // Midea
  BRAND_HAIER,           // Haier
  BRAND_SAMSUNG,         // Samsung
  BRAND_LG,              // LG
  BRAND_FUJITSU,         // Fujitsu
  BRAND_HITACHI,         // Hitachi
  BRAND_COUNT            // Total brand count
};

// AC state structure
struct ACState {
  bool power;           // Power state
  int temperature;      // Temperature (16-30°C)
  ACMode mode;          // Mode
  FanSpeed fanSpeed;    // Fan speed
  ACBrand brand;        // Brand
};

// ========== Display Parameters ==========

#define SCREEN_WIDTH  240
#define SCREEN_HEIGHT 240

// Color definitions
#define COLOR_BG      0x0000  // Black background
#define COLOR_TEXT    0xFFFF  // White text
#define COLOR_TITLE   0x07FF  // Cyan title
#define COLOR_TEMP    0xFFE0  // Yellow temperature
#define COLOR_ON      0x07E0  // Green (power on)
#define COLOR_OFF     0xF800  // Red (power off)
#define COLOR_MODE    0xFBE0  // Orange mode

// ========== Speaker Parameters ==========

#define SPEAKER_SAMPLE_RATE   16000   // Sample rate 16kHz
#define SPEAKER_VOLUME        50      // Default volume (0-100)

// ========== Microphone Parameters ==========

#define MIC_SAMPLE_RATE       16000   // Sample rate 16kHz
#define MIC_BUFFER_SIZE       512     // Buffer size for audio samples

// ========== NTP Time Configuration ==========

// If NTP is slow, switch to a closer/local server (e.g. ntp.aliyun.com).
#define NTP_SERVER_PRIMARY "time.cloudflare.com"
#define NTP_SERVER_BACKUP1 "time.nist.gov"
#define NTP_SERVER_BACKUP2 "pool.ntp.org"

#define NTP_SYNC_INTERVAL_MS 15000
#define NTP_SYNC_TIMEOUT_MS 10000

#define GMT_OFFSET_SEC     28800      // GMT+8 (Malaysia/Singapore) = 8 * 3600
#define DAYLIGHT_OFFSET_SEC 0         // No daylight saving

#endif // CONFIG_H

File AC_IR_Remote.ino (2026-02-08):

/*
 * ESP32-S3 Smart AC Remote
 */

#include "config.h"
#include "display.h"
#include "ir_control.h"
#include "ac_control.h"
#include "speaker_control.h"
#include "mic_control.h"
#include "ei_wake_word.h"  // Edge Impulse wake word detection
#include "voice_command.h"
#include "wifi_manager.h"
#include "firebase_client.h"
#include "button_control.h"
#include "ir_learning_enhanced.h"
#include "sensors.h"
#include "alarm_manager.h"
#include "mqtt_broker.h"
#include <time.h>
#include <esp_sntp.h>
#include <ctype.h>
#include <stdio.h>
#include <Adafruit_NeoPixel.h>

// Forward declarations
void handleCommand(const String& line);
void printHelp();
void printStatus();

// power, temperature, mode, fanSpeed, brand
ACState acState = {false, 24, MODE_COOL, FAN_AUTO, BRAND_GREE};

// NeoPixel RGB LED
Adafruit_NeoPixel pixels(NEOPIXEL_COUNT, NEOPIXEL_PIN, NEO_GRB + NEO_KHZ800);

static bool ntpSynced = false;
static unsigned long ntpStartMs = 0;

static void startNtpSync() {
  sntp_set_sync_mode(SNTP_SYNC_MODE_IMMED);
  sntp_set_sync_interval(NTP_SYNC_INTERVAL_MS);
  configTime(GMT_OFFSET_SEC, DAYLIGHT_OFFSET_SEC,
             NTP_SERVER_PRIMARY, NTP_SERVER_BACKUP1, NTP_SERVER_BACKUP2);
  ntpStartMs = millis();
  ntpSynced = false;
}

static void handleNtpSync() {
  if (ntpSynced) {
    return;
  }

  time_t now = time(nullptr);
  if (now > 1700000000) {
    ntpSynced = true;
    Serial.printf("[System] NTP synced in %lu ms\n", millis() - ntpStartMs);
    return;
  }

  if (millis() - ntpStartMs > NTP_SYNC_TIMEOUT_MS) {
    Serial.println("[System] NTP sync still pending (check UDP/123 or server)");
    ntpStartMs = millis();
  }
}

static void handleAutoDry(const SensorData& data) {
  static bool humidityAboveThreshold = false;
  static float lastThreshold = -1.0f;

  float threshold = getAutoDryThreshold();
  if (threshold != lastThreshold) {
    humidityAboveThreshold = false;
    lastThreshold = threshold;
  }

  if (threshold <= 0) {
    return;
  }

  if (!data.dht_valid) {
    return;
  }

  float humidity = data.dht_humidity;
  if (humidity < threshold - AUTO_DRY_HYSTERESIS) {
    humidityAboveThreshold = false;
    return;
  }

  if (!acState.power) {
    return;
  }

  if (humidityAboveThreshold) {
    return;
  }

  humidityAboveThreshold = true;
  if (acState.mode != MODE_DRY) {
    Serial.printf("[AutoDry] Humidity %.1f%% >= %.1f%%, switching to DRY\n",
                  humidity, threshold);
    acSetMode(MODE_DRY);
  }
}

static void handleSleepMode(const SensorData& data) {
  static bool lightBelowThreshold = false;
  static float lastThreshold = -1.0f;

  float threshold = getSleepLightThreshold();
  if (threshold != lastThreshold) {
    lightBelowThreshold = false;
    lastThreshold = threshold;
  }

  if (threshold <= 0) {
    return;
  }

  if (!data.light_valid) {
    return;
  }

  float lux = data.light_lux;
  if (lux > threshold + SLEEP_LIGHT_HYSTERESIS) {
    lightBelowThreshold = false;
    return;
  }

  if (!acState.power) {
    return;
  }

  if (lightBelowThreshold) {
    return;
  }

  lightBelowThreshold = true;
  if (acState.fanSpeed != FAN_LOW) {
    Serial.printf("[SleepMode] Light %.1f lx <= %.1f lx, lowering fan\n",
                  lux, threshold);
    acSetFan(FAN_LOW);
  }
}

static void printHeartbeat() {
  Serial.println("\n[Status] ------------------------------");
  Serial.printf("[Status] WiFi: %s\n", getWiFiStatus().c_str());
  Serial.printf("[Status] Firebase: %s\n", getFirebaseStatus().c_str());
  Serial.printf("[Status] MQTT: %s\n", getMqttStatus().c_str());
  Serial.printf("[Status] AC: %s\n", getACStateString().c_str());

  if (ntpSynced) {
    struct tm timeinfo;
    if (getLocalTime(&timeinfo, 0)) {
      char buf[24];
      strftime(buf, sizeof(buf), "%Y-%m-%d %H:%M:%S", &timeinfo);
      Serial.printf("[Status] Time: %s\n", buf);
    } else {
      Serial.println("[Status] NTP: synced (time unavailable)");
    }
  } else {
    Serial.println("[Status] NTP: pending");
  }
  Serial.println("[Status] ------------------------------\n");
}

// ========== Wake Word Callback (Edge Impulse) ==========

/**
 * Callback function when "Hey Bob" is detected by Edge Impulse
 * Starts voice command recording - LED is controlled by voice_command module
 * @param confidence The confidence score (0.0 - 1.0)
 */
void onWakeWordDetected(float confidence) {
  Serial.printf("\n*** WAKE WORD DETECTED: Hey Bob! (%.0f%% confidence) ***\n", confidence * 100);

  // Play a confirmation beep
  playActionTone();

  // Start voice command mode (LED controlled by voice_command module)
  startVoiceCommand();
}

void setup() {
  Serial.begin(115200);
  Serial.setTimeout(100);
  delay(1000);
  
  Serial.println("\n");
  Serial.println("========================================");
  Serial.println("  ESP32-S3 Smart AC Remote v3.0");
  Serial.println("  Firebase + WiFi + Voice Feedback");
  Serial.println("========================================");
  Serial.println();
  
  // Initialize NeoPixel RGB LED
  pixels.begin();
  pixels.clear();
  pixels.show();
  Serial.println("[System] NeoPixel initialized");
  
  // Initialize display
  initDisplay();
  showBootScreen();
  delay(2000);
  
  // Initialize sensors EARLY (before I2S to avoid I2C timing issues)
  initSensors();
  
  // Initialize IR
  initIR();
  
  // Initialize speaker
  initSpeaker();
  
  // Initialize microphone (but don't start wake word yet)
  initMicrophone();
  
  // Initialize buttons
  initButtons();

  // Initialize alarms (persistent storage)
  initAlarmManager();
  
  // Initialize IR learning (Enhanced)
  initIRLearningEnhanced();

  // Set default screen to Clock
  setScreen(SCREEN_CLOCK);
  Serial.println("[System] Default screen set to CLOCK");
  
  // Initialize WiFi Manager
  initWiFiManager();
  
  // If WiFi connected, initialize Firebase
  if (WiFi.status() == WL_CONNECTED) {
    initFirebase();
    publishAlarmsToFirebase("boot");

    initMqttBroker();
    
    // Initialize NTP for real time
    Serial.println("[System] Initializing NTP time sync...");
    startNtpSync();

    if (isFirebaseConfigured()) {
      // Queue initial state to Firebase
      firebaseQueueState(acState, "boot");
    } else {
      Serial.println("[Firebase] Not configured (update firebase_config.h)");
    }
    Serial.println("[System] OK: NTP configured");
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

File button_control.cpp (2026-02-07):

/*
 * Button Control - Implementation
 */

#include "button_control.h"
#include "display.h"
#include "speaker_control.h"
#include "wifi_manager.h"
#include "ir_learning_enhanced.h"
#include "alarm_manager.h"
#include <WiFi.h>

ScreenMode currentScreen = SCREEN_CLOCK;

struct ButtonState {
  bool lastState;
  unsigned long lastDebounceTime;
  bool pressed;
};

enum JoyDirection {
  JOY_NEUTRAL = 0,
  JOY_LEFT,
  JOY_RIGHT,
  JOY_UP,
  JOY_DOWN
};

static ButtonState joyButton = {HIGH, 0, false};

static int joyCenterX = 2048;
static int joyCenterY = 2048;
static JoyDirection lastJoyDir = JOY_NEUTRAL;
static JoyDirection pendingJoyDir = JOY_NEUTRAL;
static unsigned long lastJoyActionMs = 0;
static unsigned long pendingJoySinceMs = 0;
static unsigned long neutralSinceMs = 0;
static unsigned long lastNetworkClickMs = 0;
static bool joyArmed = true;

static const int JOY_DEADZONE = 500;
static const int JOY_TRIGGER_THRESHOLD = 900;
static const int JOY_AXIS_MARGIN = 120;
static const unsigned long JOY_ACTION_COOLDOWN_MS = 200;
static const unsigned long JOY_STABLE_MS = 80;
static const unsigned long JOY_NEUTRAL_ARM_MS = 150;
static const unsigned long JOY_DOUBLE_CLICK_MS = 500;
static const unsigned long JOY_LOG_INTERVAL_MS = 1000;
static const int JOY_CALIBRATION_SAMPLES = 8;

static const char* joyDirName(JoyDirection dir) {
  switch (dir) {
    case JOY_LEFT:
      return "LEFT";
    case JOY_RIGHT:
      return "RIGHT";
    case JOY_UP:
      return "UP";
    case JOY_DOWN:
      return "DOWN";
    default:
      return "NEUTRAL";
  }
}

static void readJoystickRaw(int* x, int* y) {
  long sumX = 0;
  long sumY = 0;
  const int samples = 3;

  for (int i = 0; i < samples; i++) {
    sumX += analogRead(JOY_X_PIN);
    sumY += analogRead(JOY_Y_PIN);
  }

  *x = (int)(sumX / samples);
  *y = (int)(sumY / samples);
}

static void calibrateJoystick() {
  long sumX = 0;
  long sumY = 0;

  for (int i = 0; i < JOY_CALIBRATION_SAMPLES; i++) {
    sumX += analogRead(JOY_X_PIN);
    sumY += analogRead(JOY_Y_PIN);
    delay(5);
  }

  joyCenterX = (int)(sumX / JOY_CALIBRATION_SAMPLES);
  joyCenterY = (int)(sumY / JOY_CALIBRATION_SAMPLES);
}

static JoyDirection resolveDirectionFromDelta(int dx, int dy) {
  int ax = abs(dx);
  int ay = abs(dy);

  if (ax < JOY_DEADZONE && ay < JOY_DEADZONE) {
    return JOY_NEUTRAL;
  }

  if (ax >= ay + JOY_AXIS_MARGIN) {
    if (ax < JOY_TRIGGER_THRESHOLD) {
      return JOY_NEUTRAL;
    }
    return (dx < 0) ? JOY_LEFT : JOY_RIGHT;
  }

  if (ay >= ax + JOY_AXIS_MARGIN) {
    if (ay < JOY_TRIGGER_THRESHOLD) {
      return JOY_NEUTRAL;
    }
    return (dy < 0) ? JOY_UP : JOY_DOWN;
  }

  return JOY_NEUTRAL;
}

static JoyDirection readJoystickDirection() {
  int x = 0;
  int y = 0;
  readJoystickRaw(&x, &y);
  int dx = x - joyCenterX;
  int dy = y - joyCenterY;

  return resolveDirectionFromDelta(dx, dy);
}

static JoyDirection pollJoystickDirection() {
  JoyDirection dir = readJoystickDirection();
  unsigned long now = millis();

  if (dir == JOY_NEUTRAL) {
    lastJoyDir = JOY_NEUTRAL;
    pendingJoyDir = JOY_NEUTRAL;
    if (neutralSinceMs == 0) {
      neutralSinceMs = now;
    }
    if (!joyArmed && (now - neutralSinceMs) >= JOY_NEUTRAL_ARM_MS) {
      joyArmed = true;
    }
    return JOY_NEUTRAL;
  }

  neutralSinceMs = 0;

  if (!joyArmed) {
    return JOY_NEUTRAL;
  }

  if (dir != pendingJoyDir) {
    pendingJoyDir = dir;
    pendingJoySinceMs = now;
    return JOY_NEUTRAL;
  }

  if (now - pendingJoySinceMs < JOY_STABLE_MS) {
    return JOY_NEUTRAL;
  }

  if (now - lastJoyActionMs < JOY_ACTION_COOLDOWN_MS) {
    return JOY_NEUTRAL;
  }

  lastJoyDir = dir;
  lastJoyActionMs = now;
  joyArmed = false;
  return dir;
}

static bool checkJoystickClick() {
  bool reading = digitalRead(JOY_SW_PIN);

  if (reading != joyButton.lastState) {
    joyButton.lastDebounceTime = millis();
    joyButton.lastState = reading;
  }

  if ((millis() - joyButton.lastDebounceTime) > DEBOUNCE_DELAY) {
    if (reading == LOW && !joyButton.pressed) {
      joyButton.pressed = true;
    }

    if (reading == HIGH && joyButton.pressed) {
      joyButton.pressed = false;
      return true;
    }
  }

  return false;
}

void initButtons() {
  Serial.println("\n========================================");
  Serial.println("  JOYSTICK INITIALIZATION START");
  Serial.println("========================================");

  analogReadResolution(12);
  pinMode(JOY_X_PIN, INPUT);
  pinMode(JOY_Y_PIN, INPUT);
  pinMode(JOY_SW_PIN, INPUT_PULLUP);

  // Serial.println("[Joystick] OK: Pins configured");
  // Serial.printf("[Joystick]   VRx: GPIO%d\n", JOY_X_PIN);
  // Serial.printf("[Joystick]   VRy: GPIO%d\n", JOY_Y_PIN);
  // Serial.printf("[Joystick]   SW : GPIO%d\n", JOY_SW_PIN);

  delay(100);
  calibrateJoystick();

  neutralSinceMs = millis();
  pendingJoyDir = JOY_NEUTRAL;
  joyArmed = true;
  lastJoyDir = JOY_NEUTRAL;

  // Serial.printf("[Joystick] Center calibrated: X=%d Y=%d\n", joyCenterX, joyCenterY);
  // Serial.printf("[Joystick] Deadzone=%d Trigger=%d Margin=%d\n",
  //               JOY_DEADZONE,
  //               JOY_TRIGGER_THRESHOLD,
  //               JOY_AXIS_MARGIN);
  // Serial.printf("[Joystick] SW initial state: %d (should be 1 when not pressed)\n",
  //               digitalRead(JOY_SW_PIN));

  // Serial.println("\n========================================");
  // Serial.println("  JOYSTICK INITIALIZATION COMPLETE");
  // Serial.println("========================================\n");
}

static void handleScreenSwitch(JoyDirection dir) {
  if (dir != JOY_LEFT && dir != JOY_RIGHT) {
    return;
  }
  if (currentScreen >= SCREEN_COUNT) {
    return;
  }

  ScreenMode oldScreen = currentScreen;

  if (dir == JOY_RIGHT) {
    currentScreen = (ScreenMode)((currentScreen + 1) % SCREEN_COUNT);
  } else {
    currentScreen = (ScreenMode)((currentScreen + SCREEN_COUNT - 1) % SCREEN_COUNT);
  }

  // Serial.println("========================================");
  // Serial.println("[Joystick] Screen switch detected!");
  // Serial.printf("[Joystick] Old screen: %d\n", oldScreen);
  // Serial.printf("[Joystick] New screen: %d\n", currentScreen);

  // const char* screenNames[] = {"VOLUME", "CLOCK", "NETWORK", "AC", "IR_LEARN", "SENSORS"};
  // Serial.printf("[Joystick] Switching: %s -> %s\n",
  //               screenNames[oldScreen], screenNames[currentScreen]);

  playBeep(1000, 50);
  delay(30);
  playBeep(1200, 50);

  updateScreenDisplay();
  // Serial.println("[Joystick] Screen updated!");
  // Serial.println("========================================");
}

static void adjustVolume(int delta) {
  int currentVol = getSpeakerVolume();
  int newVol = currentVol + delta;

  if (newVol > 100) {
    newVol = 100;
  }
  if (newVol < 0) {
    newVol = 0;
  }

  setSpeakerVolume(newVol);
  // Serial.printf("[Joystick] Volume: %d%% -> %d%%\n", currentVol, newVol);
  playBeep(delta > 0 ? 1200 : 1000, 100);
  updateScreenDisplay();
}
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

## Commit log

2026-02-05 Initial commit: ESP32 AC IR Remote with Firebase and Cloudflare dashboard
    [FYP-Enclosure_Body.stl, FYP-Enclosure_Bottom.stl, FYP-Enclosure_Holder.stl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]
2026-02-05 fix: correct dash board showing implementation
2026-02-06 feat: Add voice control prototype
2026-02-07 fix: brand error when send IR signal
    [mqtt_broker.cpp]
2026-02-07 feat: integrate enhanced IR learning system (flat 40-signal API)
    - Update AC_IR_Remote.ino to use ir_learning_enhanced.h
    - Update display.cpp for flat signal UI (Signal X/40, learned count)
    - Update button_control.cpp for UP/DOWN navigation with auto-advance
    - Update mqtt_broker.cpp with 4 new handlers (set_signal_name, send_signal, send_signal_by_name, list_signals)
    - Update aws_mqtt.cpp for backward compatibility
    - Delete old ir_learning.cpp and ir_learning.h files
    - All compilation errors resolved
    [AC_IR_Remote.ino, aws_mqtt.cpp, button_control.cpp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]
2026-02-07 fix: complete API integration for enhanced IR learning
    - Fix missing quote in AC_IR_Remote.ino include statement
    - Update button_control.cpp to use flat 40-signal API
    * Rename handleLearnDeviceStep -> handleSignalStep
    * Use getCurrentSignal/setCurrentSignal instead of device-based API
    * Add auto-advance after successful 3-capture validation
    * Update joystick click handler for new learning flow
    - Update display.cpp to show flat signal UI
    * Change from 'Device: X/5' to 'Signal: X/40'
    * Show signal name, protocol, quality score
    * Display total learned count (X/40)
    * Update instructions for signal navigation
    * Update state messages for 3-capture validation
    - Add 4 new MQTT ha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
    [AC_IR_Remote.ino, aws_mqtt.cpp, button_control.cpp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]
2026-02-07 fix: Fix IR learning system crashes and improve signal reliability
    - Reduce MAX_IR_BUFFER_SIZE from 1024 to 300 to prevent stack overflow
    - Add watchdog timer feeding during EEPROM operations to prevent resets
    - Skip repeat codes on all captures, not just first capture
    - Switch from raw timing to protocol-specific transmission (sendNEC, etc.)
    - Add NEC protocol double-send for better reliability
    - Add memory usage diagnostics on startup
    - Improve debug output for timeout and learning state tracking
    Fixes device restart during signal save and improves learned signal
    transmission success rate with IR devices.
    [AC_IR_Remote.ino, button_control.cpp, display.cpp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]
2026-02-07 fix: Change EEPRROM to use SPIFFS to store IR signal for Permanant storage
    [display.cpp, ir_learning_enhanced.cpp]
2026-02-08 feat: Add voice to text integration into ESP32 using groq api
2026-02-08 fix: Voice command visual cue color logic to blue when listening and red when response
    [AC_IR_Remote.ino, voice_command.cpp]
2026-02-08 fix: model has been decommissioned and is no longer supported for intent paraphrasing , changing to use model 'llama-3.1-8b-instant'
    [voice_command.cpp]
2026-02-09 feat(voice): add dynamic IR signal recognition and multi-brand AC support
    - Replace hardcoded actions with dynamic prompt system
    - AI decides which ir_send command based on signal names
    - Track current AC brand for default when user doesn't specify
    - Update documentation with new dynamic device setup workflow
    Voice commands now work with any named IR signal without code changes.
    Just learn signal, name it descriptively, and use voice commands.
    [audio_capture.ino, voice_command.cpp]
